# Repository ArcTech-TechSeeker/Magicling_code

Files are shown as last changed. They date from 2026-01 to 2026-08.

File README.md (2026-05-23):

# Magicling_code（nIpxel用コード）

モーション入力＆ハプティクス付き **無線コントローラ nIpxel**（ESP32 + BNO055）を中心としたコード/回路/CADである。
9 軸センサから得た姿勢・加速度を**世界座標へ変換**し、**Bluetooth SPP** でホストへ送出すると同時に、振動モータを **PWM** で制御する。

紹介サイト：https://nipxel.netlify.app/

---

## 特長

* **9軸姿勢融合**：BNO055（NDOF）から **Yaw / Pitch / Roll** と **線形加速度**を取得
* **座標安定化**：クォータニオン→回転行列で**グローバル座標系加速度**を算出
* **ジャンプ補償**：Yaw のスパイク（磁気外乱等）を短時間固定＋オフセットで自然連続化
* **ハプティクス**：振動モータを **200 Hz / 8bit PWM** で駆動（アナログ追従／点滅パターン）
* **軽量通信**：Bluetooth SPP で **固定小数バイナリ**（15 B/フレーム）を周期送信
* **2P対応**：デバイス名末尾を `"1P"` / `"2P"` で切替

---

## アーキテクチャ

```
BNO055 → (I²C) → ESP32 (LoLin32 Lite 等)
         ├─ クォータニオン姿勢 → 回転行列 → 世界座標加速度
         ├─ ジャンプ補償（Yaw offset）
         ├─ ハプティクス制御（PWM）
         └─ Bluetooth SPP（固定小数バイナリ）→ PC / ゲーム
```

---

## ハードウェア

* **MCU**：ESP32（LoLin32 Lite 等）
* **IMU**：Adafruit BNO055（I²C, アドレス `0x29`）
* **モータ**：小型振動モータ（ローサイド NPN 駆動：2SC1815）
* **ベース抵抗**：**1 kΩ（茶・黒・赤・金）**
* **フライバック**：1N400x 等（モータ端子**並列・逆向き**）

### 回路データ
回路データはCircuitフォルダ内のもの．Kicadを用いて作成されている．

PCBを発注したければ，GaberのZIPファイルを直接JLCPCBなどのサービスに発注するとよい

### CADデータ
AutodeskのInventorを用いて製作．プリントしたい場合はfor 3Dprintフォルダ内のSTLを使用

### 既定ピン

| 機能 | ESP32 ピン | 備考 |
| --- | --- | --- |
| I²C SDA  | GPIO **23** | `Wire.begin(23,19)` |
| I²C SCL  | GPIO **19** | 〃 |
| PWM（モータ） | GPIO **25** | 200 Hz / 8bit |
| LED | GPIO **22** | 動作表示 |

> 3.3 V／GND 共有。I²C は 4.7–10 kΩ のプルアップ（多くのブレークアウトに実装済み）。

---

## ファームウェア概要

### 主要ライブラリ

`Wire.h`（I²C）、`Adafruit_BNO055.h`（9軸融合）、`utility/imumaths.h`（Quat/行列）、`BluetoothSerial.h`（SPP）

### PWM 互換層

ESP32 Arduino Core v2/v3 の差異をマクロで吸収（`ledcSetup/AttachPin` vs `ledcAttach`）。

### センサ処理パイプライン

1. **取得**：BNO055 から **線形加速度**・**オイラー角**・**クォータニオン**
2. **平滑化**：加速度[g]に一次 IIR（`alpha=0.7`）
3. **座標変換**：Quat→3×3 回転行列でローカル→**世界座標系**へ
4. **Yaw 補償**：差分 > 45°（かつ < 320°）を「ジャンプ」とみなし短時間固定、後段で `yaw_offset` を適用

### ハプティクス（`Vibration()`）

* **モード選択**：SPP で `'0'..'5'` の一文字コマンド

  * `'0'`：アナログ追従（|a| からデューティ算出、下限デッドゾーン・上限クランプ）
  * `'1'..'4'`：点滅パターン（周期×デューティ）
  * `'5'`：停止

---

## Bluetooth SPP プロトコル

**1 フレーム = 15 バイト**

* 先頭ヘッダ：`'S'`（1 B）
* ペイロード：**int16 × 7**（14 B, Little-Endian）

  1. `ax_global × 100`（2桁固定小数）
  2. `ay_global × 100`
  3. `az_global × 100`
  4. `qw × 10000`（4桁固定小数）
  5. `qx × 10000`
  6. `qy × 10000`
  7. `qz × 10000`

**送信周期**：およそ **100 Hz**（`delay(10)` 目安）
**デコード（受信側）**：LE の `int16` を実数に復元（加速度÷100、Quaternion÷10000）。ヘッダ `'S'` で同期。

---

## ビルド & 書き込み

### Arduino IDE

1. ボード：ESP32 ファミリ（LoLin32 Lite 等）
2. 依存ライブラリ導入（Adafruit BNO055 ほか）
3. スケッチを書き込み

### PlatformIO / ESP-IDF

* `ledc` / `Wire` / `BluetoothSerial` が利用可能な環境設定でビルド。

---

## 起動と使用

1. 電源投入／SPP ペアリング：デバイス名は `"LOLIN32_Lite_1P"`（`name` で `"2P"` に切替可）
2. ホストは SPP で **15B 固定フレーム**を連続受信
3. 必要に応じ `'0'..'5'` を送信して**ハプティクスモード**を切替

---

## 調整可能パラメータ

| 変数 | 既定 | 説明 |
| --- | -----: | --- |
| `alpha` | 0.7 | ローパス（過去重み） |
| `pwmFreq` | 200 Hz | モータ駆動周波数 |
| `pwmResolution` |  8 bit | デューティ分解能 |
| `j_wall` |  2 ループ | Yaw 固定期間 |
| `name` | `"1P"` | SPP 名末尾 |

---

## リポジトリ構成（例）

```
Magicling_code/
├── src/                # ESP32 スケッチ/ソース
├── include/            # ヘッダ
├── hardware/           # 回路図・配線図
└── README.md
```

> 実際の構成はリポジトリに従うこと。名称や配置は変更される場合がある。

## ライセンス

リポジトリ同梱の **LICENSE** を参照。
# Magicling_code (Code for nIpxel)

This repository contains the code, circuit data, and CAD resources centered around **nIpxel**, a **wireless controller with motion input and haptics** (ESP32 + BNO055).

It converts orientation/acceleration obtained from a 9-axis sensor into the **world (global) coordinate frame**, transmits the data to a host via **Bluetooth SPP**, and controls a vibration motor using **PWM**.

Project site: https://nipxel.netlify.app/

---

## Features

- **9-axis sensor fusion**: Uses BNO055 (NDOF) to obtain **Yaw / Pitch / Roll** and **linear acceleration**
- **Coordinate stabilization**: Converts quaternion → rotation matrix to compute **global-frame acceleration**
- **Jump compensation**: Detects yaw spikes (e.g., magnetic disturbance), briefly freezes + applies an offset for smooth continuity
- **Haptics**: Drives a vibration motor at **200 Hz / 8-bit PWM** (analog follow / blink patterns)
- **Lightweight transport**: Periodically sends **fixed-point binary** frames over Bluetooth SPP (**15 B/frame**)
- **Two-player support**: Switch the device name suffix to `"1P"` / `"2P"`

---

## Architecture

```text
BNO055 → (I²C) → ESP32 (LoLin32 Lite, etc.)
         ├─ Quaternion orientation → Rotation matrix → World-frame acceleration
         ├─ Jump compensation (yaw offset)
         ├─ Haptics control (PWM)
         └─ Bluetooth SPP (fixed-point binary) → PC / game
```

---

## Hardware

- **MCU**: ESP32 (LoLin32 Lite, etc.)
- **IMU**: Adafruit BNO055 (I²C, address `0x29`)
- **Motor**: Small vibration motor (low-side NPN drive: 2SC1815)
- **Base resistor**: **1 kΩ (brown-black-red-gold)**
- **Flyback diode**: 1N400x, etc. (in parallel across motor terminals, reverse polarity)

### Circuit Data

Circuit data is located in the `Circuit` folder and was created using **KiCad**.

If you want to order a PCB, you can upload the **Gerber ZIP** directly to services such as **JLCPCB**.

### CAD Data

Designed using **Autodesk Inventor**. For 3D printing, use the STL files in the `for 3Dprint` folder.

### Default Pins

| Function | ESP32 Pin | Notes |
|---|---|---|
| I²C SDA | GPIO **23** | `Wire.begin(23,19)` |
| I²C SCL | GPIO **19** | same as above |
| PWM (motor) | GPIO **25** | 200 Hz / 8-bit |
| LED | GPIO **22** | status indicator |

> Share 3.3 V / GND. I²C requires 4.7–10 kΩ pull-ups (often included on breakout boards).

---

## Firmware Overview

### Key Libraries

`Wire.h` (I²C), `Adafruit_BNO055.h` (sensor fusion), `utility/imumaths.h` (Quat/matrix), `BluetoothSerial.h` (SPP)

### PWM Compatibility Layer

Absorbs differences between ESP32 Arduino Core v2/v3 using macros (e.g., `ledcSetup/AttachPin` vs `ledcAttach`).

### Sensor Processing Pipeline

1. **Read**: From BNO055: **linear acceleration**, **Euler angles**, **quaternion**
2. **Smoothing**: First-order IIR on acceleration [g] (`alpha=0.7`)
3. **Transform**: Quat → 3×3 rotation matrix; local → **world frame**
4. **Yaw compensation**: If delta > 45° (and < 320°), treat as a “jump”, freeze briefly; apply `yaw_offset` afterward

### Haptics (`Vibration()`)

- **Mode selection**: Send a single-character command via SPP: `'0'..'5'`

  - `'0'`: Analog follow (compute duty from |a| with deadzone and clamp)
  - `'1'..'4'`: Blink patterns (period × duty)
  - `'5'`: Stop

---

## Bluetooth SPP Protocol

**1 frame = 15 bytes**

- Header: `'S'` (1 B)
- Payload: **int16 × 7** (14 B, Little-Endian)

  1. `ax_global × 100` (fixed-point with 2 decimals)
  2. `ay_global × 100`
  3. `az_global × 100`
  4. `qw × 10000` (fixed-point with 4 decimals)
  5. `qx × 10000`
  6. `qy × 10000`
  7. `qz × 10000`

**Transmit rate**: approx. **100 Hz** (target via `delay(10)`)  
**Decode (receiver)**: Convert LE `int16` back to float (accel ÷ 100, quaternion ÷ 10000). Use header `'S'` for synchronization.

---

## Build & Flash

### Arduino IDE

1. Board: ESP32 family (LoLin32 Lite, etc.)
2. Install dependencies (Adafruit BNO055, etc.)
3. Upload the sketch

### PlatformIO / ESP-IDF

- Build with an environment where `ledc`, `Wire`, and `BluetoothSerial` are available.

---

## Startup & Usage

1. Power on / pair via SPP: device name defaults to `"LOLIN32_Lite_1P"` (set `name` to switch to `"2P"`)
2. Host continuously receives **15-byte fixed frames** over SPP
3. Send `'0'..'5'` as needed to switch **haptics modes**

---

## Tunable Parameters

| Variable | Default  | Description |
|---|---:|---|
| `alpha` | 0.7 | Low-pass filter weight |
| `pwmFreq` | 200 Hz | Motor drive frequency  |
| `pwmResolution`  |  8 bit | PWM duty resolution |
| `j_wall` | 2 loops  | Yaw freeze duration |
| `name` | `"1P"` | SPP name suffix |

---

## Repository Layout (Example)

```text
Magicling_code/
├── src/                # ESP32 sketch/source
├── include/            # headers
├── hardware/           # schematics/wiring
└── README.md
```

> Follow the actual repository structure. Names and locations may change.

---

## License

See the **LICENSE** file included in this repository.

---

## BLE OTA

The firmware exposes the same BLE OTA protocol as
`naka6ryo/RemoteCompilerToMicon` WebAppSide, without adding Wi-Fi
provisioning.

* BLE device name during the first 10 seconds after boot:
  `ESP32-nIpxel_1P` or `ESP32-nIpxel_2P`
* OTA service: `9f5f0001-8d9e-6f4e-bd0c-3c4d5e6f7180`
* Control: `START:<size>`, `END`, `ABORT`
* Data: binary firmware chunks
* Status: `READY`, `PROGRESS:x/y`, `SUCCESS`, `ERROR:*`

Use an ESP32 partition scheme with OTA slots. The VS Code/Arduino CLI settings
use `PartitionScheme=min_spiffs`, which gives the OTA app slot 1,966,080 bytes.
The PlatformIO settings use `partitions_ota_2m.csv`, matching the referenced
BLE OTA project.

## Game BLE Service

The device also exposes the game-facing BLE service used by
`BleControllerAdapter.js`.

* BLE device name after the OTA pairing window: `nIpxel_1P` or `nIpxel_2P`
* Service: `12345678-1234-1234-1234-123456789abc`
* Sensor Notify: `12345678-1234-1234-1234-123456789abd`
* Haptic Write: `12345678-1234-1234-1234-123456789abe`
* Sensor frame: 17 bytes, `S` + sequence byte + seven little-endian `int16` values + flags byte
* Haptic command: 2 bytes, `strength` and `duration` in 10 ms units

Arduino CLI build outputs are written to the workspace-local `build/` folder.

BLE advertising is mode-switched to keep Web Bluetooth filters reliable:
the first 10 seconds after boot advertise only the OTA service, and then the
device advertises only the game service. If an OTA client connects during that
initial window, OTA mode is kept active while connected.

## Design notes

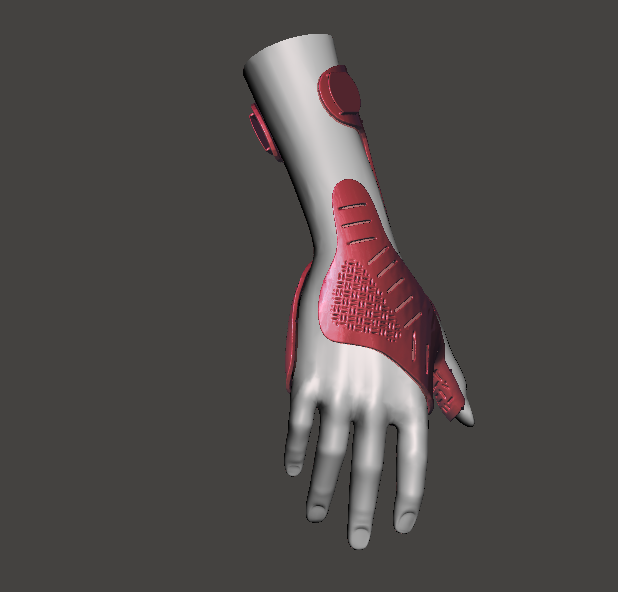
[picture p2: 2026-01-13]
3DCAD/hand-orthosis-cockup-splint-2.snapshot.1/hand-orthosis-cockup-splint/Untitled-1.png

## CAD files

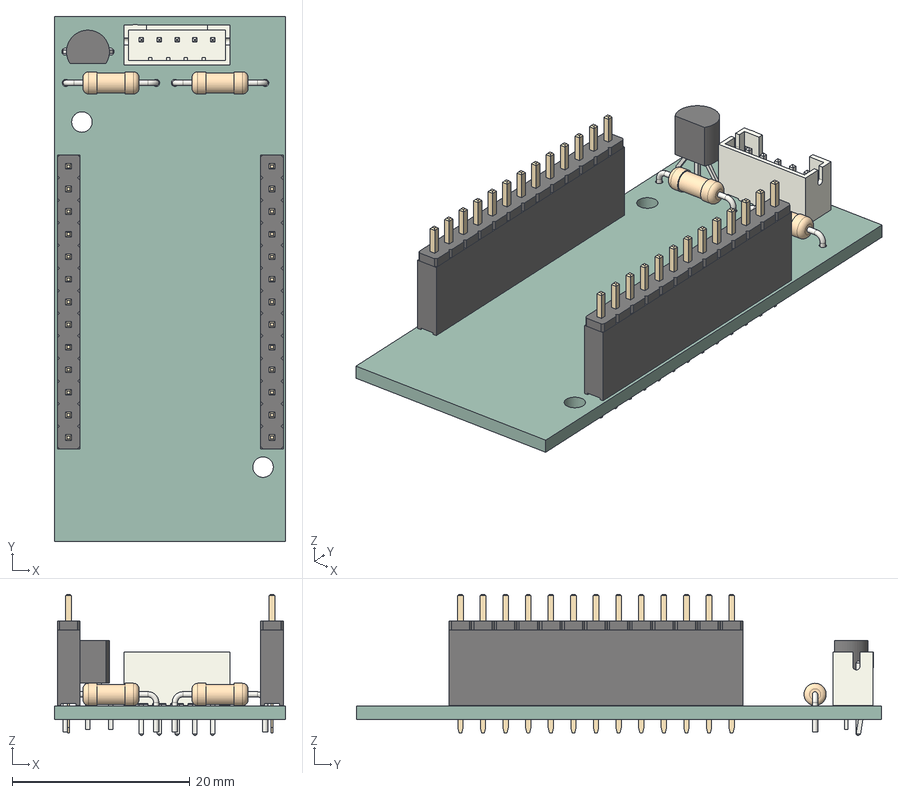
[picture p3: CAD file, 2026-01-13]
3DCAD/Cuicuit.step
26.0 x 59.0 x 15.9 mm
R_Axial_DIN0207_L6.3mm_D2.5mm_P10.16mm_Horizontal x 2
PinSocket_1x13_P2.54mm_Vertical x 2
PinHeader_1x13_P2.54mm_Vertical x 2
JST_PH_B5B-PH-K_1x05_P2.00mm_Vertical
TO-92_Inline_Wide
Cuicuit_PCB

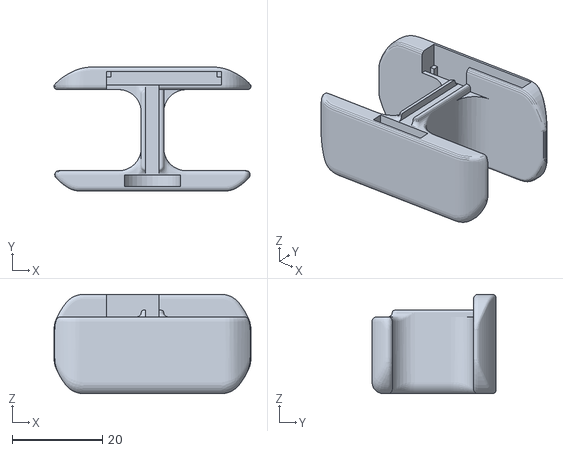
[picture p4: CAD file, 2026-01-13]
3DCAD/for 3Dprint/ring_base.stl
43.7 x 27.5 x 22.0

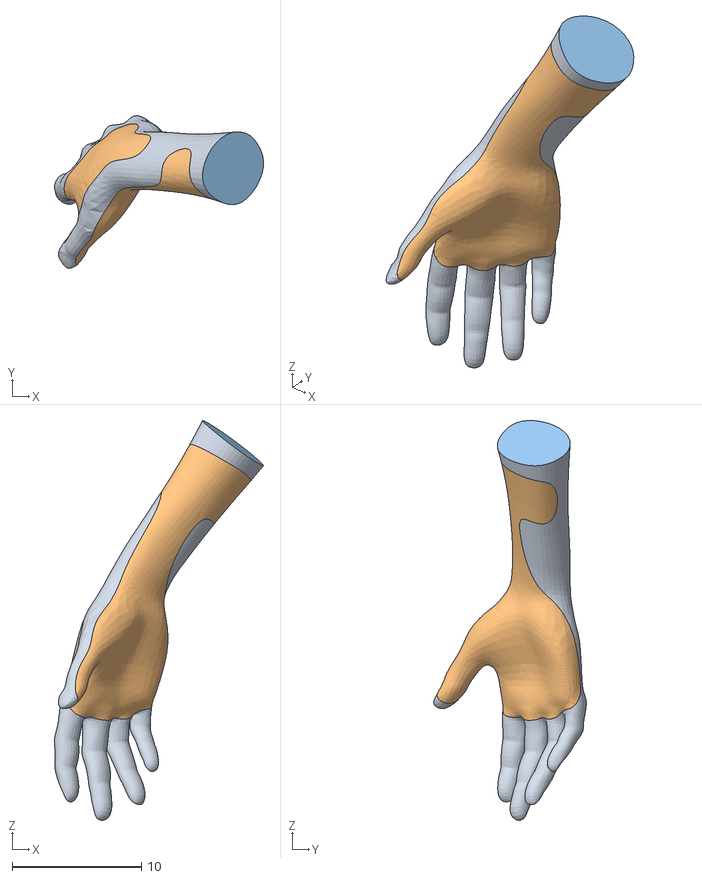
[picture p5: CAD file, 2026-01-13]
3DCAD/hand-orthosis-cockup-splint-2.snapshot.1/hand-orthosis-cockup-splint/Hand.obj
16.2 x 11.8 x 31.0
mmGroup0
mmGroup10
mmGroup11

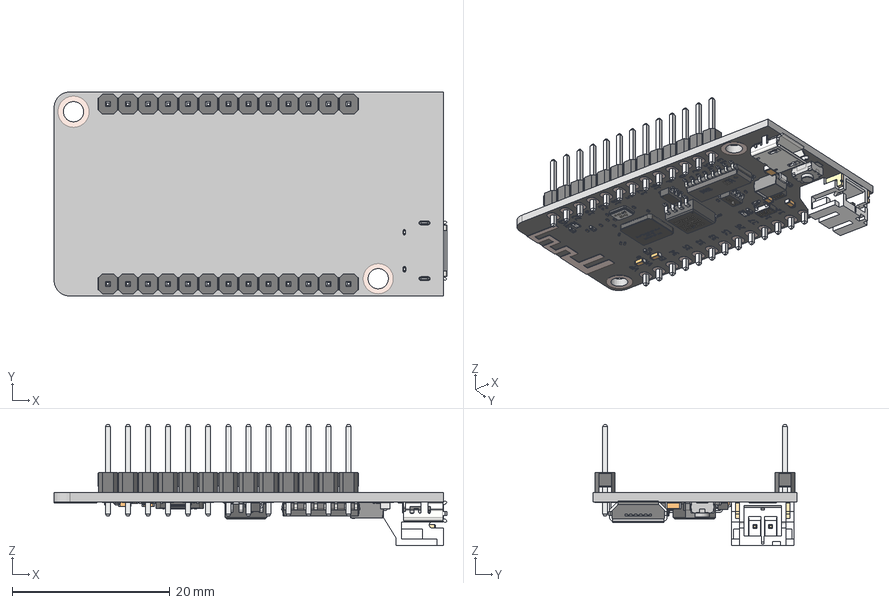
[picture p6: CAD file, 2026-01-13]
3DCAD/lolin32-lite-1.snapshot.18/Lolin32 Lite - Male Headers.step
49.8 x 25.9 x 15.3 mm
pin_1 x 20
pin x 6
JST-S2B-PH-SM4-TB
MicroUSB v1
3x4x2 tact button v1
ESP32_DOWDQ6_rev1
0603 LED v7 x 2
CH340C
40.00 MHz Oscillator
TP4054-SOT23
T25S32-SOP
ME6211-SOT23
A1SHB-SOT23
SOT23-6_PIN-GENERIC
Refdes
Cathode
Anode
Resistor 0402 x 6

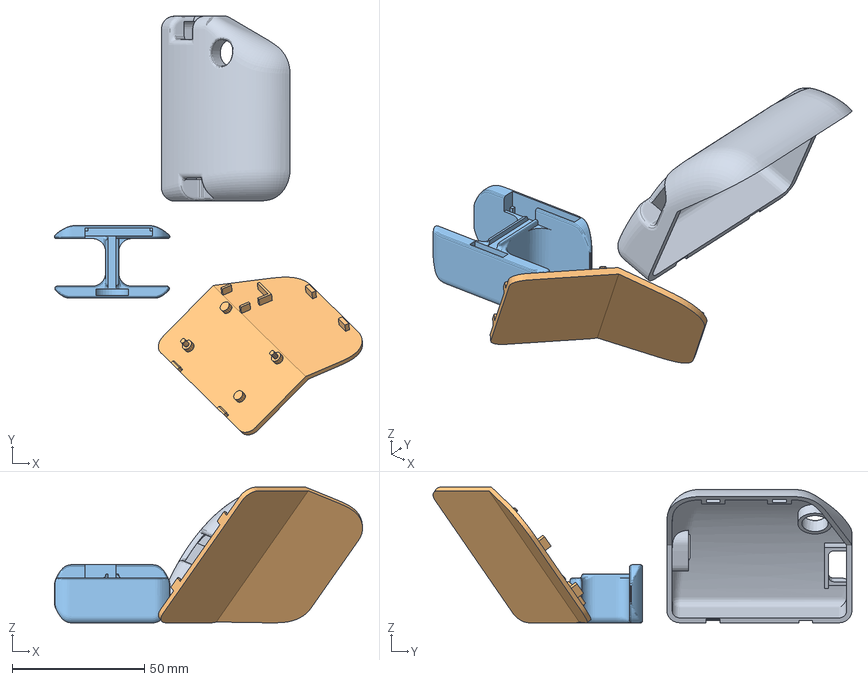
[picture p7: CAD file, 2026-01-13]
3DCAD/caber.3mf
116.5 x 158.4 x 51.3 mm
caber.stl
case.stl
ring_base.stl

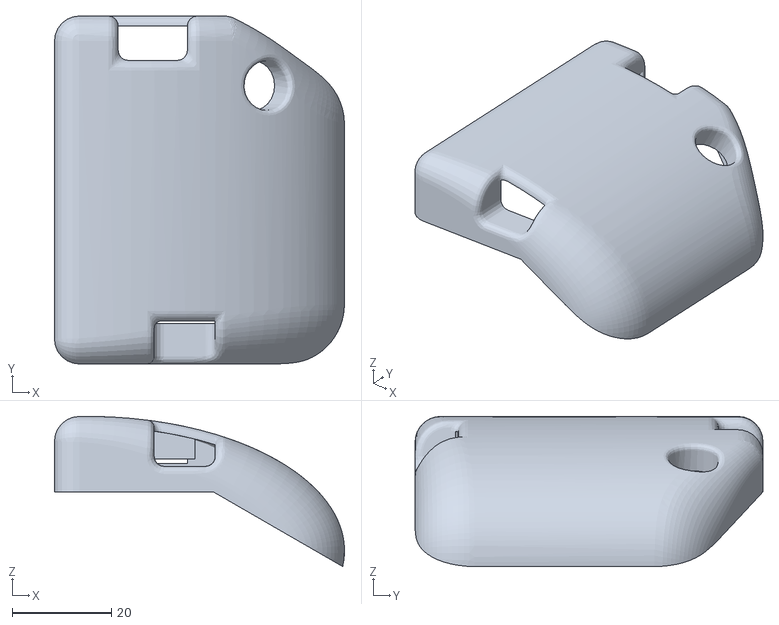
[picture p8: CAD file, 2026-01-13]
3DCAD/for 3Dprint/caber.stl
58.3 x 70.0 x 30.2

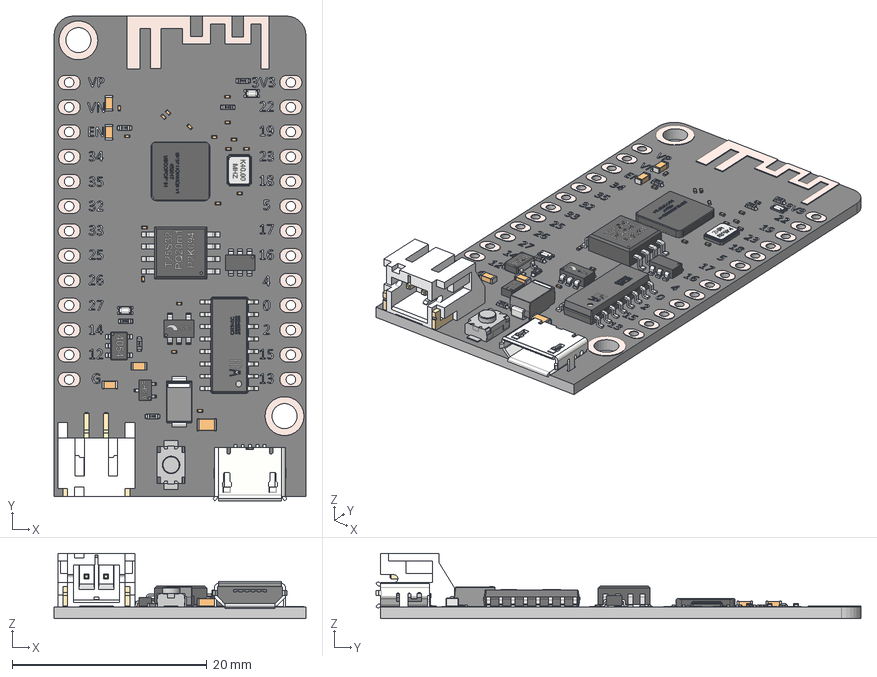
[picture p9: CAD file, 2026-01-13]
3DCAD/lolin32-lite-1.snapshot.18/Lolin 32 Lite Board.step
25.9 x 49.8 x 6.72 mm
JST-S2B-PH-SM4-TB
MicroUSB v1
3x4x2 tact button v1
ESP32_DOWDQ6_rev1
0603 LED v7 x 2
CH340C
40.00 MHz Oscillator
TP4054-SOT23
T25S32-SOP
ME6211-SOT23
A1SHB-SOT23
SOT23-6_PIN-GENERIC
Refdes
Cathode
Anode
Resistor 0402 x 6

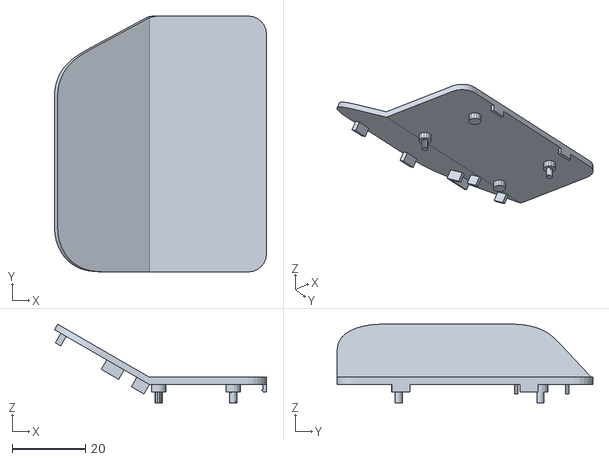
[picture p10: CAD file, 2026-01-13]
3DCAD/for 3Dprint/case.stl
58.0 x 70.0 x 21.5

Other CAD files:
Cuicuit/kicad-footprints-lolin32-lite/kicad-footprints-lolin32-lite/Sources/Inductor_SMD/L_Coilcraft_LPS5030.FCStd
Cuicuit/kicad-footprints-lolin32-lite/kicad-footprints-lolin32-lite/Sources/Package_LGA/Infineon_PG-LLGA-5-1.FCStd
Cuicuit/kicad-footprints-lolin32-lite/kicad-footprints-lolin32-lite/Sources/Package_SON/X2SON-4_1x1mm_P0.65mm.fcstd
Cuicuit/kicad-footprints-lolin32-lite/kicad-footprints-lolin32-lite/Sources/Package_TO_SOT_THT/sod-70.fcstd
Cuicuit/kicad-footprints-lolin32-lite/kicad-footprints-lolin32-lite/Sources/Inductor_SMD/L_Wuerth_WE-TPC-3816.FCStd
Cuicuit/kicad-footprints-lolin32-lite/kicad-footprints-lolin32-lite/Sources/Package_TO_SOT_THT/sod-70_P5.08mm.fcstd
3DCAD/Assembly.iam
3DCAD/BNO055.ipt
3DCAD/Cuicuit/Cuicuit.iam
3DCAD/Cuicuit/Cuicuit_PCB.ipt
3DCAD/Cuicuit/JST_PH_B5B-PH-K_1x05_P2.00mm_Vertical.ipt
3DCAD/Cuicuit/OldVersions/Cuicuit.0004.iam
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

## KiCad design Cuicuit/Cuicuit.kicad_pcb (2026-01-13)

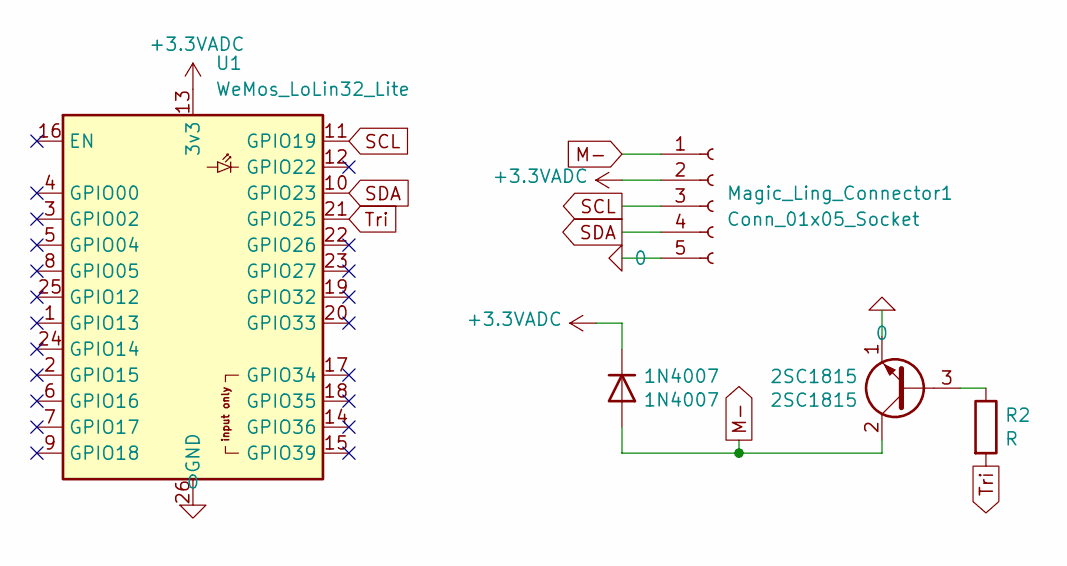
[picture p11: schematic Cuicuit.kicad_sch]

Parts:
1N4007: 1N4007; R_Axial_DIN0207_L6.3mm_D2.5mm_P10.16mm_Horizontal
2SC1815: 2SC1815; TO-92_Inline_Wide
Magic_Ling_Connector1: Conn_01x05_Socket; JST_PH_B5B-PH-K_1x05_P2.00mm_Vertical
R2: R; R_Axial_DIN0207_L6.3mm_D2.5mm_P10.16mm_Horizontal
U1: WeMos_LoLin32_Lite; WEMOS_LoLin32_Lite

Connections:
0: 2SC1815.1 (E), Magic_Ling_Connector1.5, U1.26 (GND)
+3.3VADC: 1N4007.1 (K), Magic_Ling_Connector1.2, U1.13 (3v3)
M-: 1N4007.2 (A), 2SC1815.2 (C), Magic_Ling_Connector1.1
unnamed: 2SC1815.3 (B), R2.1
SCL: Magic_Ling_Connector1.3, U1.11 (GPIO19)
SDA: Magic_Ling_Connector1.4, U1.10 (GPIO23)
Tri: R2.2, U1.21 (GPIO25)

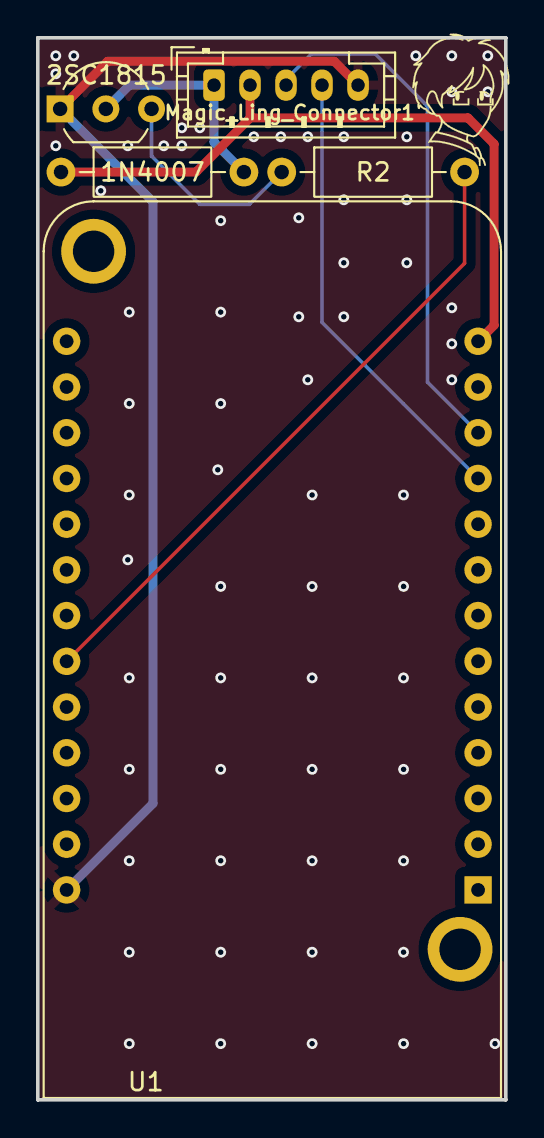
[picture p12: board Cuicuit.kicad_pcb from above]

Board: 2 copper layers, 26.0 x 59.0 mm, 5 parts (0 on the bottom side), 7 nets.

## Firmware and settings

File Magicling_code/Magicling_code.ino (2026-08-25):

#include <Wire.h>             // I2C通信を行うための標準ライブラリ
#include <Adafruit_BNO055.h>  // BNO055 9軸センサ用ライブラリ
#include <utility/imumaths.h> // ベクトルやクォータニオン演算用のユーティリティ
#include <BluetoothSerial.h>
#include <Update.h>
#include <BLEDevice.h>
#include <BLEServer.h>
#include <BLEUtils.h>
#include <BLE2902.h>
#include <esp_gap_ble_api.h>
BluetoothSerial SerialBT; // Bluetooth SPP通信用

#if defined(ARDUINO_ARCH_ESP32)
#include <Arduino.h>
                          // ESP32 Arduino コアのメジャーバージョンで分岐
#if ESP_ARDUINO_VERSION_MAJOR >= 3
#define PWM_INIT(pin, freq, res, chan) ledcAttach((pin), (freq), (res))
#define PWM_WRITE(pin, chan, value) ledcWrite((pin), (value))
#else
#define PWM_INIT(pin, freq, res, chan) \
  do                                   \
  {                                    \
    ledcSetup((chan), (freq), (res));  \
    ledcAttachPin((pin), (chan));      \
  } while (0)
#define PWM_WRITE(pin, chan, value) ledcWrite((chan), (value))
#endif
#else
#error "This sketch is for ESP32 only."
#endif

// ==== BNO055センサのインスタンス生成 ====
// 引数: センサID(任意), I2Cアドレス
Adafruit_BNO055 bno(55, 0x29);

const int LED_PIN = 22;

// 1P,2Pの指定
String name = "1P";

// PWM設定
const int motorPin = 25;     // 振動モータの制御ピン（GPIO25））
const int pwmFreq = 200;     // PWM周波数（Hz）※振動モータは低めでOK
const int pwmResolution = 8; // 分解能（8bit -> 0〜255）
const int pwmChannel = 0;

// BLE OTA UUIDs: compatible with RemoteCompilerToMicon WebAppSide.
#define DEBUG_SERVICE_UUID "7f3f0001-6b7c-4f2e-9b8a-1a2b3c4d5e6f"
#define DEBUG_LOG_TX_UUID "7f3f0002-6b7c-4f2e-9b8a-1a2b3c4d5e6f"
#define DEBUG_CMD_RX_UUID "7f3f0003-6b7c-4f2e-9b8a-1a2b3c4d5e6f"
#define DEBUG_STAT_UUID "7f3f0005-6b7c-4f2e-9b8a-1a2b3c4d5e6f"
#define OTA_SERVICE_UUID "9f5f0001-8d9e-6f4e-bd0c-3c4d5e6f7180"
#define OTA_CONTROL_UUID "9f5f0002-8d9e-6f4e-bd0c-3c4d5e6f7180"
#define OTA_DATA_UUID "9f5f0003-8d9e-6f4e-bd0c-3c4d5e6f7180"
#define OTA_STATUS_UUID "9f5f0004-8d9e-6f4e-bd0c-3c4d5e6f7180"
#define GAME_SERVICE_UUID "12345678-1234-1234-1234-123456789abc"
#define GAME_SENSOR_CHAR_UUID "12345678-1234-1234-1234-123456789abd"
#define GAME_HAPTIC_CHAR_UUID "12345678-1234-1234-1234-123456789abe"

BLEServer *otaServer = nullptr;
BLECharacteristic *debugLogCharacteristic = nullptr;
BLECharacteristic *debugStatCharacteristic = nullptr;
BLECharacteristic *otaStatusCharacteristic = nullptr;
BLECharacteristic *gameSensorCharacteristic = nullptr;
enum BlePairingMode
{
  BLE_PAIRING_OTA,
  BLE_PAIRING_GAME,
};
BlePairingMode blePairingMode = BLE_PAIRING_OTA;
bool bleClientConnected = false;
bool bleOtaConnected = false;
bool otaPairingLocked = false;
bool otaModeActive = false;
bool otaInProgress = false;
bool otaFinalizeRequested = false;
bool otaAbortRequested = false;
size_t otaExpectedSize = 0;
size_t otaReceivedSize = 0;
size_t otaLastReportedSize = 0;
unsigned long otaModeStartedMs = 0;
unsigned long otaLastActivityMs = 0;
const unsigned long OTA_MODE_TIMEOUT_MS = 60000;
const unsigned long OTA_TRANSFER_IDLE_TIMEOUT_MS = 30000;
const unsigned long OTA_PAIRING_WINDOW_MS = 10000;
const unsigned long GAME_NOTIFY_INTERVAL_MS = 20;
unsigned long lastGameNotifyMs = 0;
uint8_t directHapticStrength = 0;
unsigned long directHapticUntilMs = 0;
bool pwmReady = false;
uint8_t sensorSequence = 0;

int in = '0', in0 = '0'; // シリアル入力値（前回値と現在値） 初期値は'0'
int l = 0;               // メインループカウンタ

// ==== ローパスフィルタ用変数 ====
// alpha: 過去データの残す割合（0.0〜1.0）
float alpha = 0.7;
float ax_f = 0, ay_f = 0, az_f = 0; // ローパス適用後の加速度

// ==== 手動Yawゼロ設定 ====
// 自動ジャンプ補償は行わず、'5'入力時のゼロ設定だけに使用する。
float yaw_offset = 0;

// roll:ロール角
// pitch:ピッチ角
float roll = 0, pitch = 0, pitch_pre = 0;

// ==== 時間計測用変数 ====
unsigned long prevMicros = 0; // 前回のループ開始時刻（µs）

// ==== センサー取得結果を保持する変数 ====
// linAcc: ローカル座標系の線形加速度（重力成分除去済み）
// euler: オイラー角（Yaw, Roll, Pitch）
// mag: 磁気ベクトル
// quat: クォータニオン姿勢
imu::Vector<3> linAcc, euler, mag;
imu::Quaternion quat;
imu::Quaternion quat_corrected;

// ==== ユーティリティ関数 ====
// ±180°の範囲に角度を正規化する（何度でも繰り返して収める）
float normalize180(float angle)
{
  while (angle > 180.0f)
    angle -= 360.0f;
  while (angle <= -180.0f)
    angle += 360.0f;
  return angle;
}

float yawFromQuaternion(const imu::Quaternion &q)
{
  float qw = q.w(), qx = q.x(), qy = q.y(), qz = q.z();
  float yaw_deg = atan2f(2.0f * (qx * qy + qz * qw),
                         1.0f - 2.0f * (qy * qy + qz * qz)) *
                  180.0f / PI;
  return normalize180(yaw_deg);
}

imu::Quaternion yawCorrectionQuaternion(float yaw_deg)
{
  float yaw_rad = yaw_deg * PI / 180.0f;
  imu::Quaternion correction(cosf(yaw_rad * 0.5f), 0.0f, 0.0f, sinf(yaw_rad * 0.5f));
  correction.normalize();
  return correction;
}

imu::Quaternion normalizedForSend(imu::Quaternion q)
{
  q.normalize();
  if (q.w() < 0.0f)
  {
    q = q * -1.0;
  }
  return q;
}

imu::Quaternion applyYawCorrection(const imu::Quaternion &source, float offset_deg)
{
  imu::Quaternion corrected = yawCorrectionQuaternion(-offset_deg) * source;
  return normalizedForSend(corrected);
}

// ==== センサー値の取得とローパスフィルタ適用 ====
// BNO055から加速度・姿勢情報を取得し、加速度はローパス処理
void readSensors()
{
  // センサーから各種データを取得
  linAcc = bno.getVector(Adafruit_BNO055::VECTOR_LINEARACCEL);
  quat = bno.getQuat();
  euler = bno.getVector(Adafruit_BNO055::VECTOR_EULER);
  mag = bno.getVector(Adafruit_BNO055::VECTOR_MAGNETOMETER);

  // 加速度値をg単位に変換しローパスフィルタ適用
  float ax = linAcc.x() / 9.8;
  float ay = linAcc.y() / 9.8;
  float az = linAcc.z() / 9.8;
  ax_f = alpha * ax_f + (1 - alpha) * ax;
  ay_f = alpha * ay_f + (1 - alpha) * ay;
  az_f = alpha * az_f + (1 - alpha) * az;
}

// ==== クォータニオン→回転行列変換し、加速度をグローバル座標系に変換 ====
// 出力: ax_global, ay_global, az_global
void calcGlobalAcceleration(float &ax_global, float &ay_global, float &az_global)
{
  // クォータニオンから回転行列を生成
  float qw = quat.w(), qx = quat.x(), qy = quat.y(), qz = quat.z();
  float R[3][3] = {
      {1 - 2 * (qy * qy + qz * qz), 2 * (qx * qy - qz * qw), 2 * (qx * qz + qy * qw)},
      {2 * (qx * qy + qz * qw), 1 - 2 * (qx * qx + qz * qz), 2 * (qy * qz - qx * qw)},
      {2 * (qx * qz - qy * qw), 2 * (qy * qz + qx * qw), 1 - 2 * (qx * qx + qy * qy)}};
  // ローカル加速度をグローバル座標に変換
  ax_global = R[0][0] * ax_f + R[0][1] * ay_f + R[0][2] * az_f;
  ay_global = R[1][0] * ax_f + R[1][1] * ay_f + R[1][2] * az_f;
  az_global = R[2][0] * ax_f + R[2][1] * ay_f + R[2][2] * az_f;
}

void updaterollandpitch()
{
  pitch_pre = pitch;

  // クォータニオンから回転行列を生成
  float qw = quat.w(), qx = quat.x(), qy = quat.y(), qz = quat.z();
  float R[3][3] = {
      {1 - 2 * (qy * qy + qz * qz), 2 * (qx * qy - qz * qw), 2 * (qx * qz + qy * qw)},
      {2 * (qx * qy + qz * qw), 1 - 2 * (qx * qx + qz * qz), 2 * (qy * qz - qx * qw)},
      {2 * (qx * qz - qy * qw), 2 * (qy * qz + qx * qw), 1 - 2 * (qx * qx + qy * qy)}};

  // ZYX（yaw-pitch-roll）系の式で roll/pitch を算出
  // roll（X軸回り）は非中間角のため -180..180 を取り得る
  float r21 = R[2][1]; // R[3][2]
  float r22 = R[2][2]; // R[3][3]
  float r20 = R[2][0]; // R[3][1]

  // roll = atan2(R32, R33) [deg]
  pitch = atan2f(r21, r22) * 180.0f / PI;

  // pitch = atan2(-R31, sqrt(R32^2 + R33^2)) [deg]
  // asin よりも数値的に安定（ゼロ割れや誤差増幅を抑制）
  float denom = sqrtf(r21 * r21 + r22 * r22);
  roll = atan2f(-r20, denom) * 180.0f / PI;

  // 表示範囲を整える
  roll = -normalize180(roll);
  pitch = -normalize180(pitch);

  if (abs(roll) >= 90)
  {
    pitch = pitch - 180;
  }
}

// 加速度ベクトルの大きさに基づいて振動モータを制御する関数
void Vibration(float ax_global, float ay_global, float az_global)
{
  if (millis() < directHapticUntilMs)
  {
    PWM_WRITE(motorPin, pwmChannel, directHapticStrength);
    return;
  }
  else if (directHapticStrength != 0)
  {
    directHapticStrength = 0;
    PWM_WRITE(motorPin, pwmChannel, 0);
  }

  in0 = in;
  // 入力チェック: Bluetooth優先、なければUSB Serial
  if (SerialBT.available() > 0)
  {
    in = SerialBT.read();
  }
  else if (Serial.available() > 0)
  {
    in = Serial.read();
  }
  else
  {
    in = in0;
  }

  // '5'へ切り替わった瞬間だけ、その時点のYawを0にする。
  // 押下後に毎ループYawを再計算すると、±90°特異点を再び通るため連続実行しない。
  if (in == '5' && in0 != '5')
  {
    // 手動操作時だけQuaternionからYawを求める。
    float yaw_raw = yawFromQuaternion(quat);
    yaw_offset = yaw_raw;
  }

  // 想定外の文字は無視して直前の値に戻す
  if (in < '0' || in > '5')
    in = in0;

  // '0' が送られてきたらアナログ振動モード
  if (in == '0')
  {
    // グローバル座標系での加速度ベクトルの大きさ（重力込み）を計算
    // √(ax^2 + ay^2 + az^2) → 全方向の加速度の合成値
    float a_pure = sqrt(ax_global * ax_global +
                        ay_global * ay_global +
                        az_global * az_global);

    // 加速度の値を 3 乗して感度を調整し、スケーリング係数300を掛けて PWM 値に変換
    // 3乗することで小さい加速度変化に対して感度を下げ、大きい加速度で急に強くなるカーブになる
    int vib = a_pure * 40;

    // 上限値を 250 に制限（PWM 8bit の最大255に近い値）
    if (vib > 250)
      vib = 250;
    // 下限閾値60未満はモータ停止（物理的に動かない領域をカット）
    else if (vib < 10)
      vib = 0;

    // PWM出力で振動モータを駆動
    PWM_WRITE(motorPin, pwmChannel, vib);
  }
  else
  {
    int flashRate = 0;
    float flashRate_deno = 0;
    if (in == '1')
    {
      flashRate = 20;
      flashRate_deno = 0.4;
    }
    else if (in == '2')
    {
      flashRate = 40;
      flashRate_deno = 0.2;
    }
    else if (in == '3')
    {
      flashRate = 80;
      flashRate_deno = 0.125;
    }
    else if (in == '4')
    {
      flashRate = 100;
      flashRate_deno = 0.9;
    }
    // '5' またはその他は安全に停止（flashRate=0のまま）
    if (flashRate > 0)
    {
      bool motorOn = (l % flashRate < (int)(flashRate * flashRate_deno));
      PWM_WRITE(motorPin, pwmChannel, motorOn ? 255 : 0);
    }
    else
    {
      PWM_WRITE(motorPin, pwmChannel, 0);
    }
  }
}

// ===============================
// データ送信（シリアル通信）
// ===============================
// Send seven values over Bluetooth:
//  - Accel ax, ay, az as fixed-point (2 decimals): value * 100 -> int16
//  - Quaternion qw, qx, qy, qz as fixed-point (4 decimals): value * 10000 -> int16
void buildSensorPayload(uint8_t *payload, float ax_global, float ay_global, float az_global, const imu::Quaternion &quat_val)
{
  int16_t ax_to_send = (int16_t)roundf(ax_global * 100.0f);
  int16_t ay_to_send = (int16_t)roundf(ay_global * 100.0f);
  int16_t az_to_send = (int16_t)roundf(az_global * 100.0f);
  imu::Quaternion q = normalizedForSend(quat_val);
  int16_t qw_to_send = (int16_t)roundf(q.w() * 10000.0f);
  int16_t qx_to_send = (int16_t)roundf(q.x() * 10000.0f);
  int16_t qy_to_send = (int16_t)roundf(q.y() * 10000.0f);
  int16_t qz_to_send = (int16_t)roundf(q.z() * 10000.0f);

  memcpy(payload + 0 * sizeof(int16_t), &ax_to_send, sizeof(int16_t));
  memcpy(payload + 1 * sizeof(int16_t), &ay_to_send, sizeof(int16_t));
  memcpy(payload + 2 * sizeof(int16_t), &az_to_send, sizeof(int16_t));
  memcpy(payload + 3 * sizeof(int16_t), &qw_to_send, sizeof(int16_t));
  memcpy(payload + 4 * sizeof(int16_t), &qx_to_send, sizeof(int16_t));
  memcpy(payload + 5 * sizeof(int16_t), &qy_to_send, sizeof(int16_t));
  memcpy(payload + 6 * sizeof(int16_t), &qz_to_send, sizeof(int16_t));
}

void buildSerialSensorFrame(uint8_t *frame, float ax_global, float ay_global, float az_global, const imu::Quaternion &quat_val)
{
  frame[0] = 'S';
  buildSensorPayload(frame + 1, ax_global, ay_global, az_global, quat_val);
}

void buildGameSensorFrame(uint8_t *frame, float ax_global, float ay_global, float az_global, const imu::Quaternion &quat_val)
{
  frame[0] = 'S';
  frame[1] = sensorSequence++;
  buildSensorPayload(frame + 2, ax_global, ay_global, az_global, quat_val);
  frame[16] = 0;
}

void outputDataAsBytes(float ax_global, float ay_global, float az_global, const imu::Quaternion &quat_val)
{
  uint8_t frame[1 + sizeof(int16_t) * 7];
  buildSerialSensorFrame(frame, ax_global, ay_global, az_global, quat_val);

  SerialBT.write(frame, sizeof(frame));

  unsigned long nowMs = millis();
  if (bleOtaConnected && gameSensorCharacteristic && !otaInProgress &&
      nowMs - lastGameNotifyMs >= GAME_NOTIFY_INTERVAL_MS)
  {
    lastGameNotifyMs = nowMs;
    uint8_t gameFrame[17];
    buildGameSensorFrame(gameFrame, ax_global, ay_global, az_global, quat_val);
    gameSensorCharacteristic->setValue(gameFrame, sizeof(gameFrame));
    gameSensorCharacteristic->notify();
  }
}

// ==== セットアップ処理 ====
// ハードウェア初期化、BNO055設定、M5Stack画面初期化
void notifyOtaStatus(const char *status)
{
  if (!otaStatusCharacteristic)
    return;

  otaStatusCharacteristic->setValue((uint8_t *)status, strlen(status));
  otaStatusCharacteristic->notify();
}

void notifyDebugLog(const char *message)
{
  if (!bleOtaConnected || !debugLogCharacteristic || otaInProgress)
    return;

  debugLogCharacteristic->setValue((uint8_t *)message, strlen(message));
  debugLogCharacteristic->notify();
}

void updateDebugStatus()
{
  if (!debugStatCharacteristic)
    return;

  char status[64];
  snprintf(status, sizeof(status), "STATE:BLE=%d,WIFI=0,OTA_MODE=%d,IP=0.0.0.0",
           bleOtaConnected ? 1 : 0,
           otaModeActive ? 1 : 0);
  debugStatCharacteristic->setValue((uint8_t *)status, strlen(status));
  if (bleOtaConnected)
    debugStatCharacteristic->notify();
}

String getGameBleName()
{
  return "nIpxel_" + name;
}

String getOtaBleName()
{
  return "ESP32-" + getGameBleName();
}

void startBleAdvertising(BlePairingMode mode)
{
  blePairingMode = mode;

  BLEAdvertising *advertising = BLEDevice::getAdvertising();
  advertising->stop();
  delay(20);

  String bleName = (mode == BLE_PAIRING_OTA) ? getOtaBleName() : getGameBleName();
  esp_ble_gap_set_device_name(bleName.c_str());

  BLEAdvertisementData advertisementData;
  advertisementData.setFlags(0x06);
  advertisementData.setCompleteServices(BLEUUID(mode == BLE_PAIRING_OTA ? OTA_SERVICE_UUID : GAME_SERVICE_UUID));
  if (mode == BLE_PAIRING_GAME)
    advertisementData.setName(bleName.c_str());

  BLEAdvertisementData scanResponseData;
  scanResponseData.setName(bleName.c_str());

  advertising->setAdvertisementData(advertisementData);
  advertising->setScanResponseData(scanResponseData);
  advertising->setScanResponse(true);
  advertising->setMinPreferred(0x06);
  advertising->setMaxPreferred(0x12);
  advertising->start();

  Serial.printf("[BLE] Advertising %s as %s\n", mode == BLE_PAIRING_OTA ? "OTA" : "GAME", bleName.c_str());
}

void updateBlePairingMode()
{
  if (bleClientConnected || otaInProgress || otaFinalizeRequested)
    return;

  unsigned long nowMs = millis();
  bool otaWindowExpired = nowMs - otaModeStartedMs >= OTA_PAIRING_WINDOW_MS;
  bool otaIdleExpired = otaPairingLocked && (nowMs - otaLastActivityMs >= OTA_MODE_TIMEOUT_MS);

  if (blePairingMode == BLE_PAIRING_OTA && otaWindowExpired && (!otaPairingLocked || otaIdleExpired))
  {
    otaModeActive = false;
    otaPairingLocked = false;
    startBleAdvertising(BLE_PAIRING_GAME);
    updateDebugStatus();
  }
}

class MagiclingOtaServerCallbacks : public BLEServerCallbacks
{
  void onConnect(BLEServer *server)
  {
    bleClientConnected = true;
    bleOtaConnected = true;
    otaLastActivityMs = millis();
    if (blePairingMode == BLE_PAIRING_OTA)
    {
      otaPairingLocked = true;
      otaModeActive = true;
    }
    notifyDebugLog("[BLE] Magicling connected");
    updateDebugStatus();
  }

  void onDisconnect(BLEServer *server)
  {
    bleClientConnected = false;
    bleOtaConnected = false;
    otaLastActivityMs = millis();
    if (otaInProgress || blePairingMode == BLE_PAIRING_OTA)
      startBleAdvertising(BLE_PAIRING_OTA);
    else
      startBleAdvertising(BLE_PAIRING_GAME);
  }
};

class MagiclingDebugCommandCallbacks : public BLECharacteristicCallbacks
{
  void onWrite(BLECharacteristic *characteristic)
  {
    auto rxValue = characteristic->getValue();
    if (rxValue.length() == 0)
      return;

    String command(rxValue.c_str());
    command.trim();

    if (command == "OTA_MODE")
    {
      otaModeActive = true;
      otaPairingLocked = true;
      otaLastActivityMs = millis();
      notifyDebugLog("[OTA] OTA mode enabled");
      updateDebugStatus();
    }
    else if (command == "STATUS")
    {
      updateDebugStatus();
    }
    else if (command == "ABORT")
    {
      otaAbortRequested = true;
    }
  }
};

class GameHapticCallbacks : public BLECharacteristicCallbacks
{
  void onWrite(BLECharacteristic *characteristic)
  {
    size_t len = characteristic->getLength();
    if (len < 2)
      return;

    uint8_t *data = characteristic->getData();
    directHapticStrength = data[0];
    uint16_t durationMs = (uint16_t)data[1] * 10;

    if (directHapticStrength == 0 || durationMs == 0)
    {
      directHapticStrength = 0;
      directHapticUntilMs = 0;
      if (pwmReady)
        PWM_WRITE(motorPin, pwmChannel, 0);
      return;
    }

    directHapticUntilMs = millis() + durationMs;
    if (pwmReady)
      PWM_WRITE(motorPin, pwmChannel, directHapticStrength);
  }
};

class MagiclingOtaControlCallbacks : public BLECharacteristicCallbacks
{
  void onWrite(BLECharacteristic *characteristic)
  {
    auto rxValue = characteristic->getValue();
    if (rxValue.length() == 0)
      return;

    String command(rxValue.c_str());
    command.trim();

    if (command.startsWith("START:"))
    {
      otaLastActivityMs = millis();
      size_t size = command.substring(6).toInt();
      size_t updateSpace = ESP.getFreeSketchSpace() & 0xFFFFF000;
      if (size == 0 || size > updateSpace)
      {
        notifyOtaStatus("ERROR:INVALID_SIZE");
        return;
      }

      otaExpectedSize = size;
      otaReceivedSize = 0;
      otaLastReportedSize = 0;
      otaFinalizeRequested = false;
      otaAbortRequested = false;
      otaModeActive = true;
      otaPairingLocked = true;

      if (!Update.begin(size, U_FLASH))
      {
        Update.printError(Serial);
        otaInProgress = false;
        notifyOtaStatus("ERROR:BEGIN_FAILED");
        return;
      }

      otaInProgress = true;
      PWM_WRITE(motorPin, pwmChannel, 0);
      notifyOtaStatus("READY");
      Serial.printf("[BLE OTA] START:%u\n", size);
    }
    else if (command == "END")
    {
      otaLastActivityMs = millis();
      if (!otaInProgress)
      {
        notifyOtaStatus("ERROR:NOT_STARTED");
        return;
      }

      if (otaReceivedSize != otaExpectedSize)
      {
        notifyOtaStatus("ERROR:INCOMPLETE");
        Serial.printf("[BLE OTA] Incomplete: %u / %u\n", otaReceivedSize, otaExpectedSize);
        return;
      }

      otaFinalizeRequested = true;
    }
    else if (command == "ABORT")
    {
      otaLastActivityMs = millis();
      otaAbortRequested = true;
    }
  }
};

class MagiclingOtaDataCallbacks : public BLECharacteristicCallbacks
{
  void onWrite(BLECharacteristic *characteristic)
  {
    if (!otaInProgress)
      return;

    size_t len = characteristic->getLength();
    if (len == 0)
      return;
    otaLastActivityMs = millis();

    if (otaReceivedSize + len > otaExpectedSize)
    {
      Update.abort();
      otaInProgress = false;
      notifyOtaStatus("ERROR:OVERFLOW");
      return;
    }

    size_t written = Update.write(characteristic->getData(), len);
    if (written != len)
    {
      Update.printError(Serial);
      Update.abort();
      otaInProgress = false;
      notifyOtaStatus("ERROR:WRITE_FAILED");
      return;
    }

    otaReceivedSize += written;
    if (otaReceivedSize - otaLastReportedSize >= 102400 || otaReceivedSize == otaExpectedSize)
    {
      otaLastReportedSize = otaReceivedSize;
      Serial.printf("[BLE OTA] Progress: %u / %u\n", otaReceivedSize, otaExpectedSize);

      if (otaReceivedSize == otaExpectedSize || otaReceivedSize % 204800 == 0)
      {
        char progress[40];
        snprintf(progress, sizeof(progress), "PROGRESS:%u/%u", otaReceivedSize, otaExpectedSize);
        notifyOtaStatus(progress);
      }
    }
  }
};
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
void loop()
{
  handleBleOta();
  updateBlePairingMode();
  if (otaInProgress || otaFinalizeRequested || otaAbortRequested)
  {
    delay(10);
    return;
  }

  // 経過時間（秒）を計算（今回は未使用だが処理間隔確認に使える）
  float dt = (micros() - prevMicros) / 1e6;
  prevMicros = micros();

  readSensors(); // センサー読み込み＆LPF適用
  if (isnan(linAcc.x()) || isnan(quat.w()) || isnan(euler.x()))
  {
    Serial.println("読み取り失敗 → スキップ");
    delay(10);
    // 再取得
    readSensors();

    // まだダメなら加速度0として続行
    if (isnan(linAcc.x()) || isnan(quat.w()) || isnan(euler.x()))
    {
      Serial.println("再試行失敗 → デフォルト値で続行");
      ax_f = 0;
      ay_f = 0;
      az_f = 0;
    }
  }

  float ax_global, ay_global, az_global;
  updaterollandpitch();
  calcGlobalAcceleration(ax_global, ay_global, az_global); // グローバル加速度算出
  Vibration(ax_global, ay_global, az_global);
  // 自動ジャンプ補償は行わない。通常時は生Quaternionを正規化して送信する。
  // '5'で手動ゼロ設定された場合のみ、明示的なYawオフセットを適用する。
  quat_corrected = applyYawCorrection(quat, yaw_offset);
  // Bluetooth通信で情報の送信（ax,ay,az,qw,qx,qy,qz を固定小数で送る）
  outputDataAsBytes(ax_global, ay_global, az_global, quat_corrected);

  // ループカウンタ更新（4000を超えたら1に戻す）
  l++;
  if (l > 4000)
    l = 1;

  // デバッグ用に加速度・Yaw値をシリアル出力
  // Serial.printf("%.3f,%.3f \n", ax_f, euler.x());
  delay(10); // CPU負荷低減
}

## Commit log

2025-07-31 VScode上での書き込みの実装
2025-07-31 攻撃判定時に画面を白く光らす
2025-08-01 attack時の向いている向きの取得の試み（Yawのオイラーの値の飛びを判定して補正する）
2025-08-01 Yaw角の値の飛びの修正
2025-08-01 コードを関数を用いて整理，コメントの追加
2025-08-01 attack_yawの文字の色の変更
2025-08-02 振動モータ機能の追加（加速度により強さが変化）
2025-08-06 Bluetooth通信と詠唱状態（Spell：指を立てる，Spell2：動かし続ける）の追加
2025-08-06 名前変更
2025-08-08 ちょい変
2025-08-21 Lolin用の更新およびライブラシの整理
2025-08-21 ライブラリ対応
2025-08-22 判定の微調整
2025-09-24 加速度と３軸角度の通信
2025-09-27 受信の改良
2025-10-06 方向修正プログラムの実装
2025-10-07 ピッチとロール角の取得方法変更でのヨー角の精度向上（ピッチ・ロールはまだ変・・・今回はいいけど今後直していきたい）
2025-10-21 Add README with game overview and technical details
    Added detailed game overview, features, architecture, hardware specifications, firmware summary, and usage instructions for the '詠印魔道' game and associated code.
2026-01-13 Add CAD data and Circuit data
    [0603 LED v7 v1.ipt, 3 pin male header v1.0001.iam, 3 pin male header v1.iam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]
2026-01-13 Update README with project introduction and data details
    Added introduction and details about circuit and CAD data.
2026-05-22 Add initial project files and configuration for OTA updates
    - Created ELF, MAP, and partition binary files for the Magicling project.
    - Added partition configuration in `partitions_ota_2m.csv` for OTA updates.
    - Set up PlatformIO configuration in `platformio.ini` for the lolin32_lite board.
    - Defined source and library directories for the project structure.
    [partitions_ota_2m.csv]
2026-05-23 Add ArduinoJson and Madgwick libraries
    - Added ArduinoJson version header file to define the library version.
    - Introduced Madgwick library with implementation of the MadgwickAHRS algorithm for orientation estimation using accelerometer and gyroscope data.
    - Included README documentation for the Madgwick library detailing its usage and licensing.
    - Implemented core functionality in MadgwickAHRS.cpp and declared necessary functions in MadgwickAHRS.h.
    [partitions.csv]
2026-05-23 Remove Madgwick library files and add flatten build script
    - Deleted the Madgwick library files including README, source implementation, and header files.
    - Added a new script `flatten_build.py` to streamline the build process by copying the firmware binary to a flat build directory.
    - Updated `platformio.ini` to include the new script in the build process.
    [partitions.csv]
2026-08-25 Add ArduinoJson and Madgwick libraries
    - Introduced ArduinoJson library version 7.4.2 with version header.
    - Added Madgwick library for IMU and AHRS algorithms, including:
    - README documentation.
    - Implementation files: MadgwickAHRS.cpp and MadgwickAHRS.h.
    - Functions for quaternion updates and angle calculations.
    [partitions.csv]
